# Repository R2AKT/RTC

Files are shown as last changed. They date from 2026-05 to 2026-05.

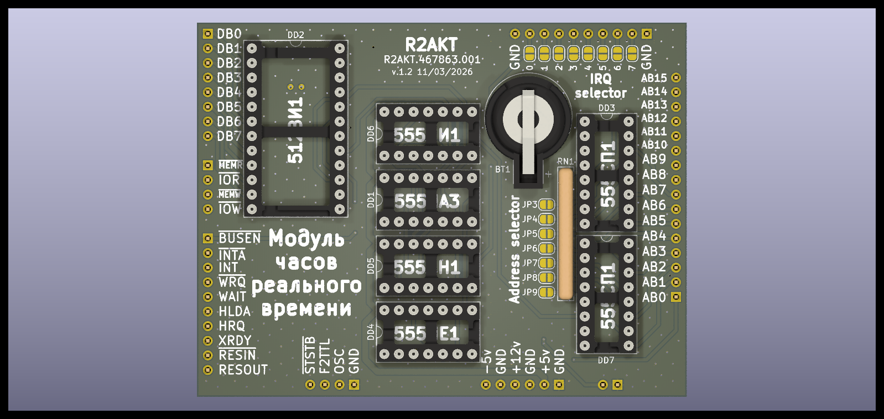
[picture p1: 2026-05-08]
RTC_top.png

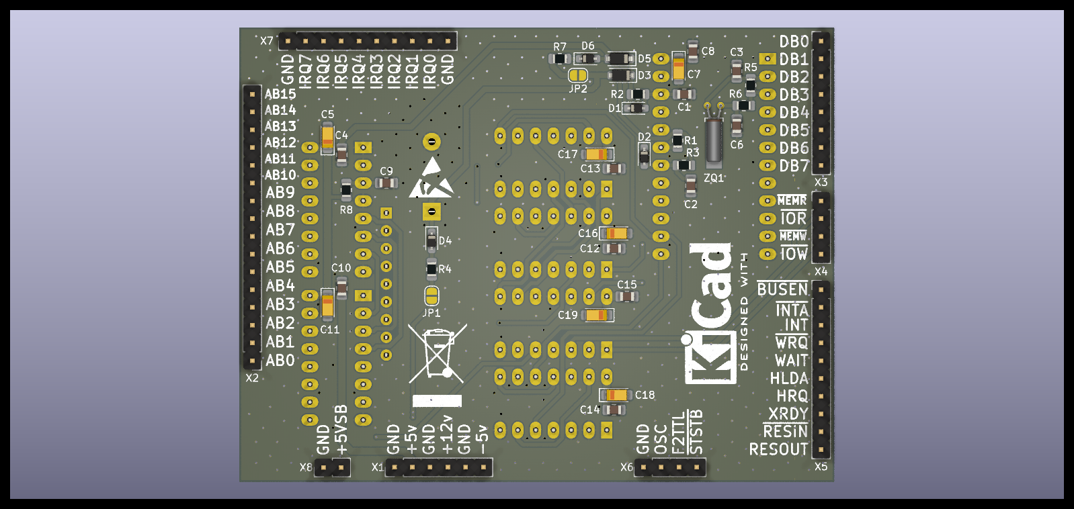
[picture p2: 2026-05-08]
RTC_btn.png

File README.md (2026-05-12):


License addendum - https://github.com/R2AKT/RTC/blob/main/Addendum.txt
# RTC
Real-time clock module (RTC). For connection to the CPU_8080 processor board - https://github.com/R2AKT/CPU_8080.

Based on a real-time clock for RADIO-86RK.

Status: testing and writing the driver.

Модуль часов реального времени (RTC). Для подключения к процессорной плате CPU_8080 - https://github.com/R2AKT/CPU_8080.

На базе часов реального времени для РАДИО-86РК.

Статус: в процессе тестирования и написания драйвера.

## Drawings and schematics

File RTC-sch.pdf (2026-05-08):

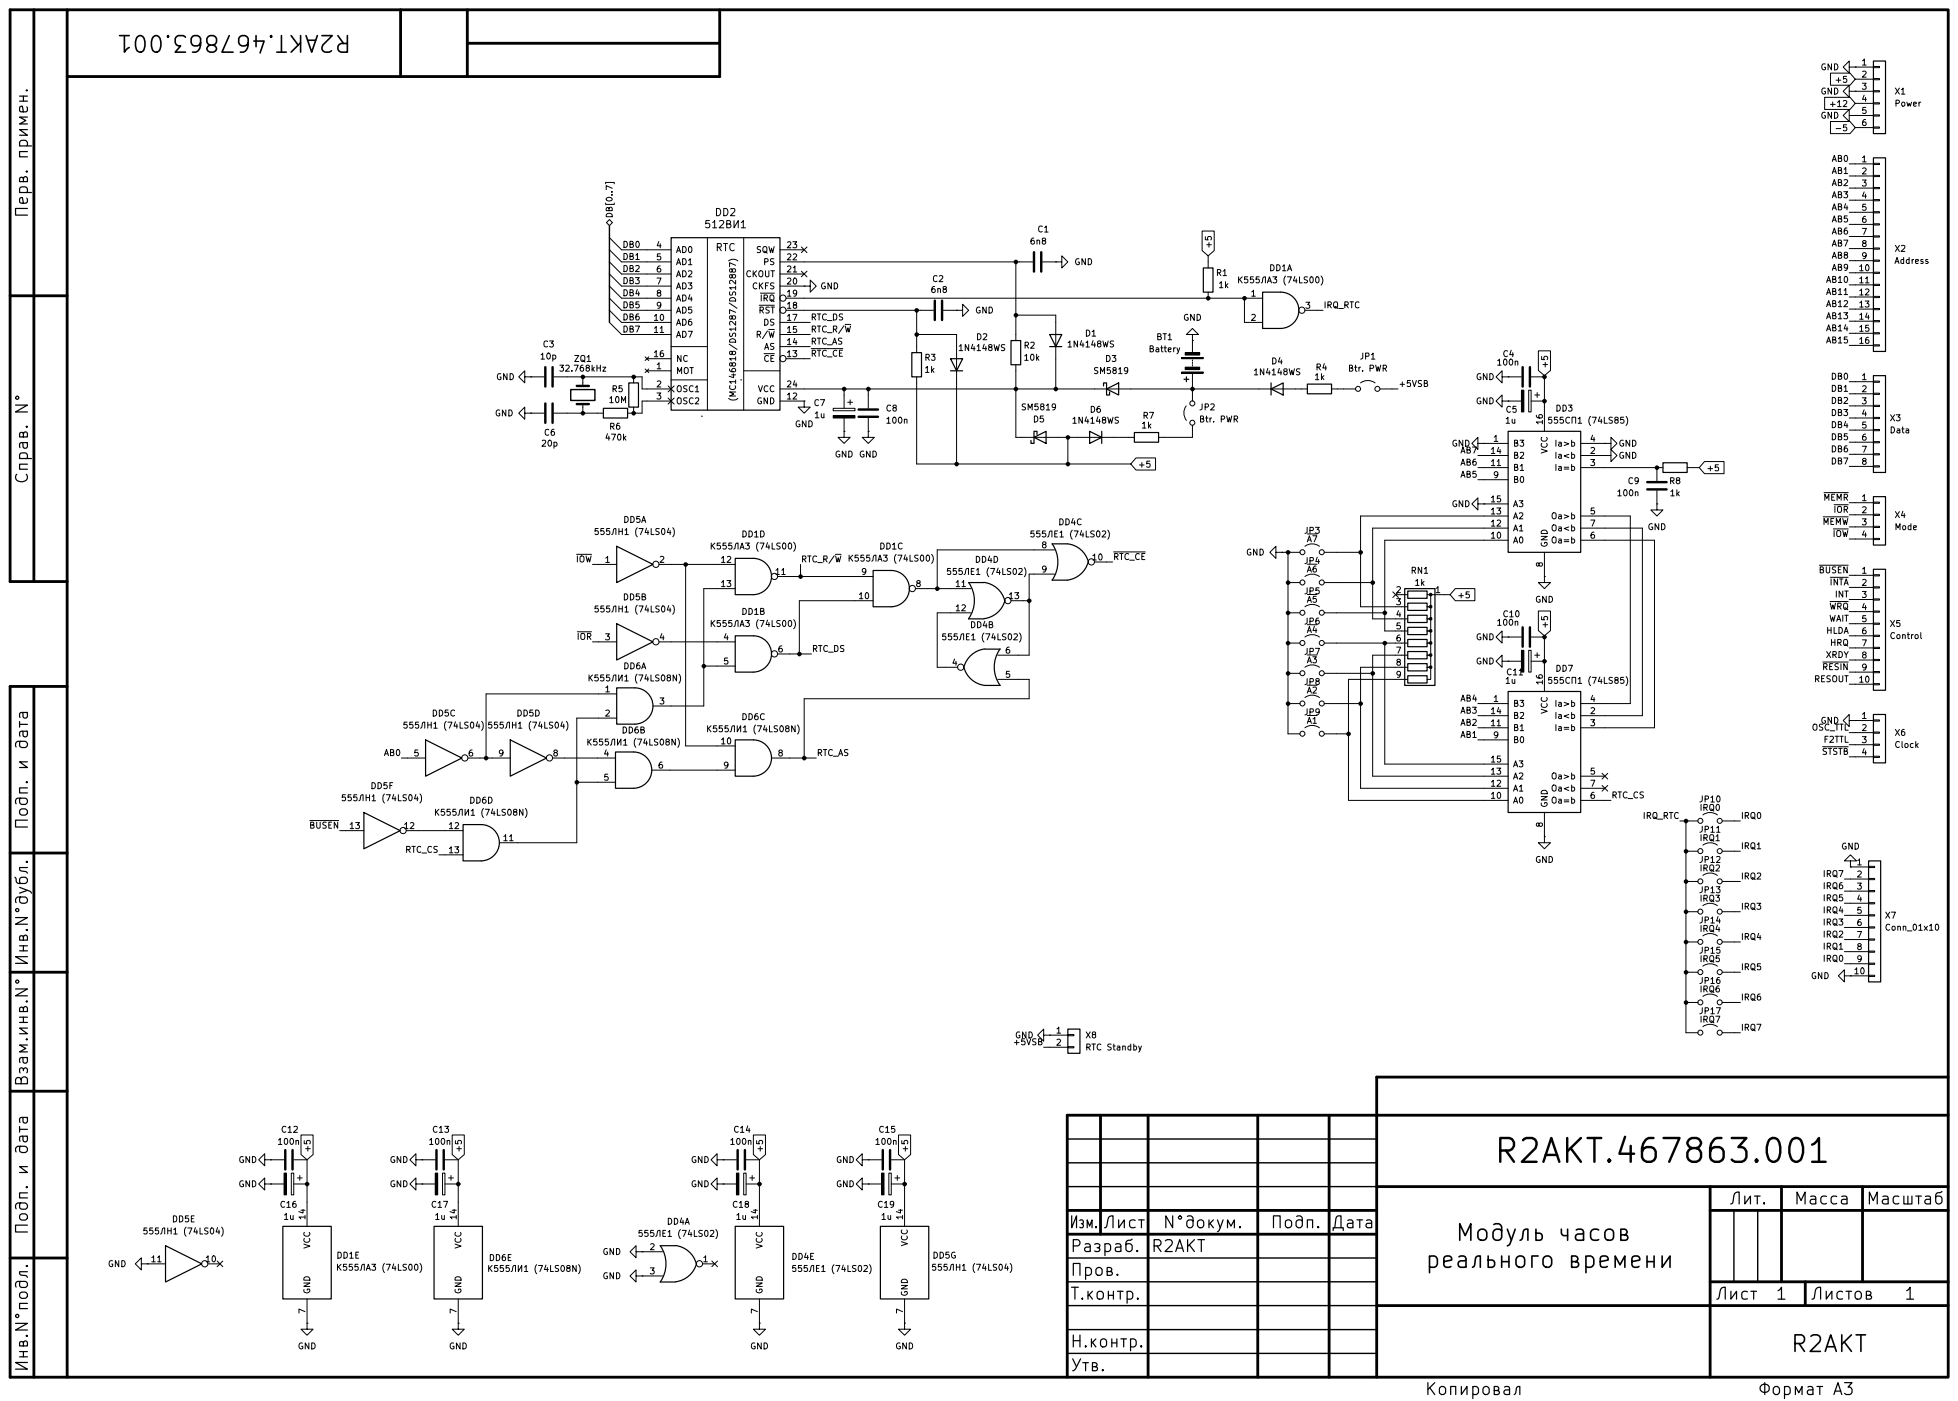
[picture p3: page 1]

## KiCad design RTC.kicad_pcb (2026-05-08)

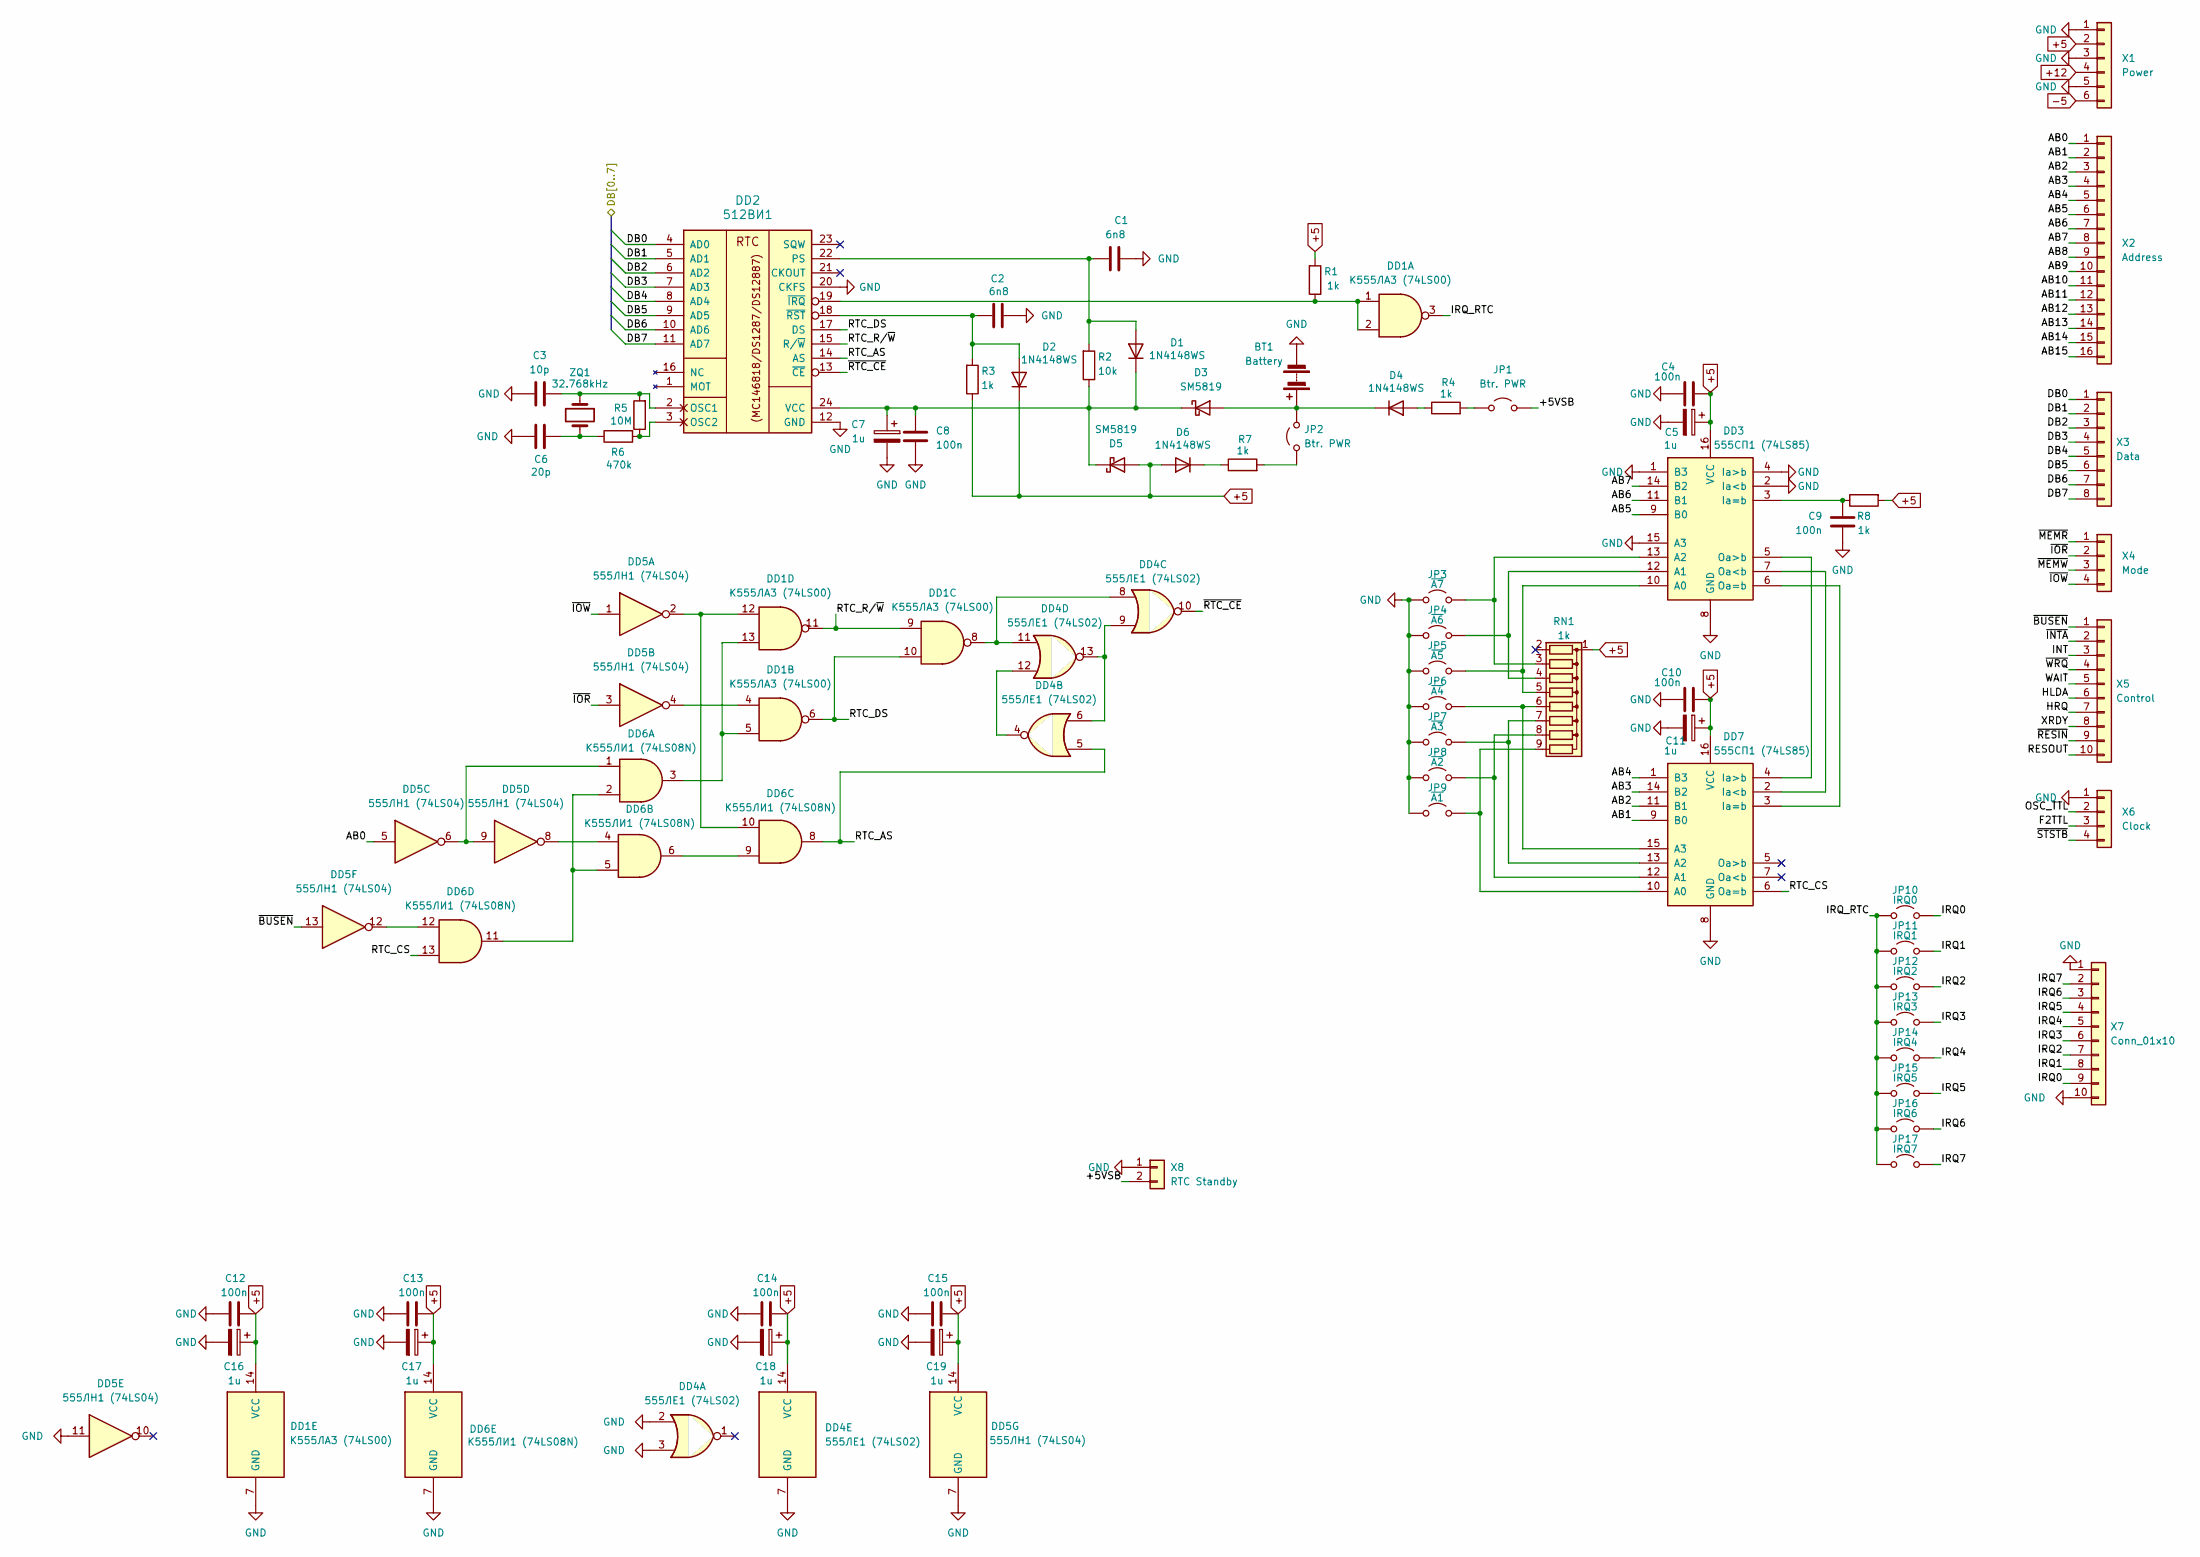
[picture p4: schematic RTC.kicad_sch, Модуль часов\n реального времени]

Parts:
BT1: Battery; BatteryHolder_Keystone_500
C1, C2: 6n8; C_0805_2012Metric_Pad1.18x1.45mm_HandSolder
C3: 10p; C_0805_2012Metric_Pad1.18x1.45mm_HandSolder
C4, C8, C9, C10, C12, C13, C14, C15: 100n; C_0805_2012Metric_Pad1.18x1.45mm_HandSolder
C5, C7, C11, C16, C17, C18, C19: 1u; CP_EIA-3216-18_Kemet-A_Pad1.58x1.35mm_HandSolder
C6: 20p; C_0805_2012Metric_Pad1.18x1.45mm_HandSolder
D1, D2, D4, D6: 1N4148WS; D_SOD-323_HandSoldering
D3: SM5819; D_SOD-123F
D5: SM5819; D_SOD-123
DD1: К555ЛА3 (74LS00); DIP-14_W7.62mm_Socket_LongPads
DD2: 512ВИ1; DIP-24_W15.24mm_Socket_LongPads
DD3, DD7: 555СП1 (74LS85); DIP-16_W7.62mm_Socket_LongPads
DD4: 555ЛЕ1 (74LS02); DIP-14_W7.62mm_Socket_LongPads
DD5: 555ЛН1 (74LS04); DIP-14_W7.62mm_Socket_LongPads
DD6: К555ЛИ1 (74LS08N); DIP-14_W7.62mm_Socket_LongPads
JP1, JP2: Btr. PWR; SolderJumper-2_P1.3mm_Open_RoundedPad1.0x1.5mm
JP3: ~{A7}; SolderJumper-2_P1.3mm_Open_RoundedPad1.0x1.5mm
JP4: ~{A6}; SolderJumper-2_P1.3mm_Open_RoundedPad1.0x1.5mm
JP5: ~{A5}; SolderJumper-2_P1.3mm_Open_RoundedPad1.0x1.5mm
JP6: ~{A4}; SolderJumper-2_P1.3mm_Open_RoundedPad1.0x1.5mm
JP7: ~{A3}; SolderJumper-2_P1.3mm_Open_RoundedPad1.0x1.5mm
JP8: ~{A2}; SolderJumper-2_P1.3mm_Open_RoundedPad1.0x1.5mm
JP9: ~{A1}; SolderJumper-2_P1.3mm_Open_RoundedPad1.0x1.5mm
JP10: IRQ0; SolderJumper-2_P1.3mm_Open_RoundedPad1.0x1.5mm
JP11: IRQ1; SolderJumper-2_P1.3mm_Open_RoundedPad1.0x1.5mm
JP12: IRQ2; SolderJumper-2_P1.3mm_Open_RoundedPad1.0x1.5mm
JP13: IRQ3; SolderJumper-2_P1.3mm_Open_RoundedPad1.0x1.5mm
JP14: IRQ4; SolderJumper-2_P1.3mm_Open_RoundedPad1.0x1.5mm
JP15: IRQ5; SolderJumper-2_P1.3mm_Open_RoundedPad1.0x1.5mm
JP16: IRQ6; SolderJumper-2_P1.3mm_Open_RoundedPad1.0x1.5mm
JP17: IRQ7; SolderJumper-2_P1.3mm_Open_RoundedPad1.0x1.5mm
R1, R3, R4, R7, R8: 1k; R_0805_2012Metric_Pad1.20x1.40mm_HandSolder
R2: 10k; R_0805_2012Metric_Pad1.20x1.40mm_HandSolder
R5: 10M; R_0805_2012Metric_Pad1.20x1.40mm_HandSolder
R6: 470k; R_0805_2012Metric_Pad1.20x1.40mm_HandSolder
RN1: 1k; R_Array_SIP9
X1: Power; PinHeader_1x06_P2.54mm_Vertical
X2: Address; PinHeader_1x16_P2.54mm_Vertical
X3: Data; PinHeader_1x08_P2.54mm_Vertical
X4: Mode; PinHeader_1x04_P2.54mm_Vertical
X5: Control; PinHeader_1x10_P2.54mm_Vertical
X6: Clock; PinHeader_1x04_P2.54mm_Vertical
X7: Conn_01x10; PinHeader_1x10_P2.54mm_Vertical
X8: RTC Standby; PinHeader_1x02_P2.54mm_Vertical
ZQ1: 32.768kHz; Crystal_C26-LF_D2.1mm_L6.5mm_Horizontal_1EP_style1

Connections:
+5: C4.1, C5.1, C10.1, C11.1, C12.1, C13.1, C14.1, C15.1, C16.1, C17.1, C18.1, C19.1, D2.1 (K), D5.2 (A), D6.2 (A), DD1.14 (VCC), DD3.16 (VCC), DD4.14 (VCC), DD5.14 (VCC), DD6.14 (VCC), DD7.16 (VCC), R1.2, R3.1, R8.2, RN1.1 (common), X1.2
+12: X1.4
-5: X1.6
/+5VSB: JP1.2 (B), X8.2
/AB0: DD5.5, X2.1
/AB1: DD7.9 (B0), X2.2
/AB2: DD7.11 (B1), X2.3
/AB3: DD7.14 (B2), X2.4
/AB4: DD7.1 (B3), X2.5
/AB5: DD3.9 (B0), X2.6
/AB6: DD3.11 (B1), X2.7
/AB7: DD3.14 (B2), X2.8
/AB8: X2.9
/AB9: X2.10
/AB10: X2.11
/AB11: X2.12
/AB12: X2.13
/AB13: X2.14
/AB14: X2.15
/AB15: X2.16
/DB0: DD2.4 (AD0), X3.1
/DB1: DD2.5 (AD1), X3.2
/DB2: DD2.6 (AD2), X3.3
/DB3: DD2.7 (AD3), X3.4
/DB4: DD2.8 (AD4), X3.5
/DB5: DD2.9 (AD5), X3.6
/DB6: DD2.10 (AD6), X3.7
/DB7: DD2.11 (AD7), X3.8
/F2TTL: X6.3
/HLDA: X5.6
/HRQ: X5.7
/INT: X5.3
/IRQ0: JP10.2 (B), X7.9
/IRQ1: JP11.2 (B), X7.8
/IRQ2: JP12.2 (B), X7.7
/IRQ3: JP13.2 (B), X7.6
/IRQ4: JP14.2 (B), X7.5
/IRQ5: JP15.2 (B), X7.4
/IRQ6: JP16.2 (B), X7.3
/IRQ7: JP17.2 (B), X7.2
/IRQ_RTC: DD1.3, JP10.1 (A), JP11.1 (A), JP12.1 (A), JP13.1 (A), JP14.1 (A), JP15.1 (A), JP16.1 (A), JP17.1 (A)
/OSC_TTL: X6.2
/RESOUT: X5.10
/RTC_AS: DD2.14 (AS), DD4.5, DD6.8
/RTC_CS: DD6.13, DD7.6 (Oa=b)
/RTC_DS: DD1.6, DD1.10, DD2.17 (DS)
/RTC_R/~W: DD1.9, DD1.11, DD2.15 (R/~W)
/WAIT: X5.5
/XRDY: X5.8
/~BUSEN: DD5.13, X5.1
/~INTA: X5.2
/~IOR: DD5.3, X4.2
/~IOW: DD5.1, X4.4
/~MEMR: X4.1
/~MEMW: X4.3
/~RESIN: X5.9
/~RTC_CE: DD2.13 (~CE), DD4.10
/~STSTB: X6.4
/~WRQ: X5.4
GND: BT1.2 (-), C1.2, C2.2, C3.1, C4.2, C5.2, C6.1, C7.2, C8.2, C9.2, C10.2, C11.2, C12.2, C13.2, C14.2, C15.2, C16.2, C17.2, C18.2, C19.2, DD1.7 (GND), DD2.12 (GND), DD2.20 (CKFS), DD3.1 (B3), DD3.2 (Ia<b), DD3.4 (Ia>b), DD3.8 (GND), DD3.15 (A3), DD4.2, DD4.3, DD4.7 (GND), DD5.7 (GND), DD5.11, DD6.7 (GND), DD7.8 (GND), JP3.1 (A), JP4.1 (A), JP5.1 (A), JP6.1 (A), JP7.1 (A), JP8.1 (A), JP9.1 (A), X1.1, X1.3, X1.5, X6.1, X7.1, X7.10, X8.1
unnamed: BT1.1 (+), D3.2 (A), D4.1 (K), JP2.2 (B)
unnamed: C6.2, R6.1, ZQ1.2
unnamed: C1.1, D1.2 (A), DD2.22 (PS), R2.2
unnamed: C7.1, C8.1, D1.1 (K), D3.1 (K), D5.1 (K), DD2.24 (VCC), R2.1
unnamed: C2.1, D2.2 (A), DD2.18 (~RST), R3.2
unnamed: D4.2 (A), R4.1
unnamed: D6.1 (K), R7.1
unnamed: DD1.4, DD5.4
unnamed: DD1.8, DD4.8, DD4.11
unnamed: DD1.12, DD5.2, DD6.10
unnamed: DD1.5, DD1.13, DD6.3
unnamed: C3.2, DD2.2 (OSC1), R5.2, ZQ1.1
unnamed: DD2.3 (OSC2), R5.1, R6.2
unnamed: DD1.1, DD1.2, DD2.19 (~IRQ), R1.1
unnamed: DD3.10 (A0), JP5.2 (B), RN1.5 (R4)
unnamed: DD3.12 (A1), JP4.2 (B), RN1.4 (R3)
unnamed: DD3.13 (A2), JP3.2 (B), RN1.3 (R2)
unnamed: C9.1, DD3.3 (Ia=b), R8.1
unnamed: DD3.7 (Oa<b), DD7.2 (Ia<b)
unnamed: DD3.6 (Oa=b), DD7.3 (Ia=b)
unnamed: DD3.5 (Oa>b), DD7.4 (Ia>b)
unnamed: DD4.4, DD4.12
unnamed: DD4.6, DD4.9, DD4.13
unnamed: DD5.6, DD5.9, DD6.1
unnamed: DD5.8, DD6.4
unnamed: DD5.12, DD6.12
unnamed: DD6.6, DD6.9
unnamed: DD6.2, DD6.5, DD6.11
unnamed: DD7.10 (A0), JP9.2 (B), RN1.9 (R8)
unnamed: DD7.12 (A1), JP8.2 (B), RN1.8 (R7)
unnamed: DD7.13 (A2), JP7.2 (B), RN1.7 (R6)
unnamed: DD7.15 (A3), JP6.2 (B), RN1.6 (R5)
unnamed: JP1.1 (A), R4.2
unnamed: JP2.1 (A), R7.2

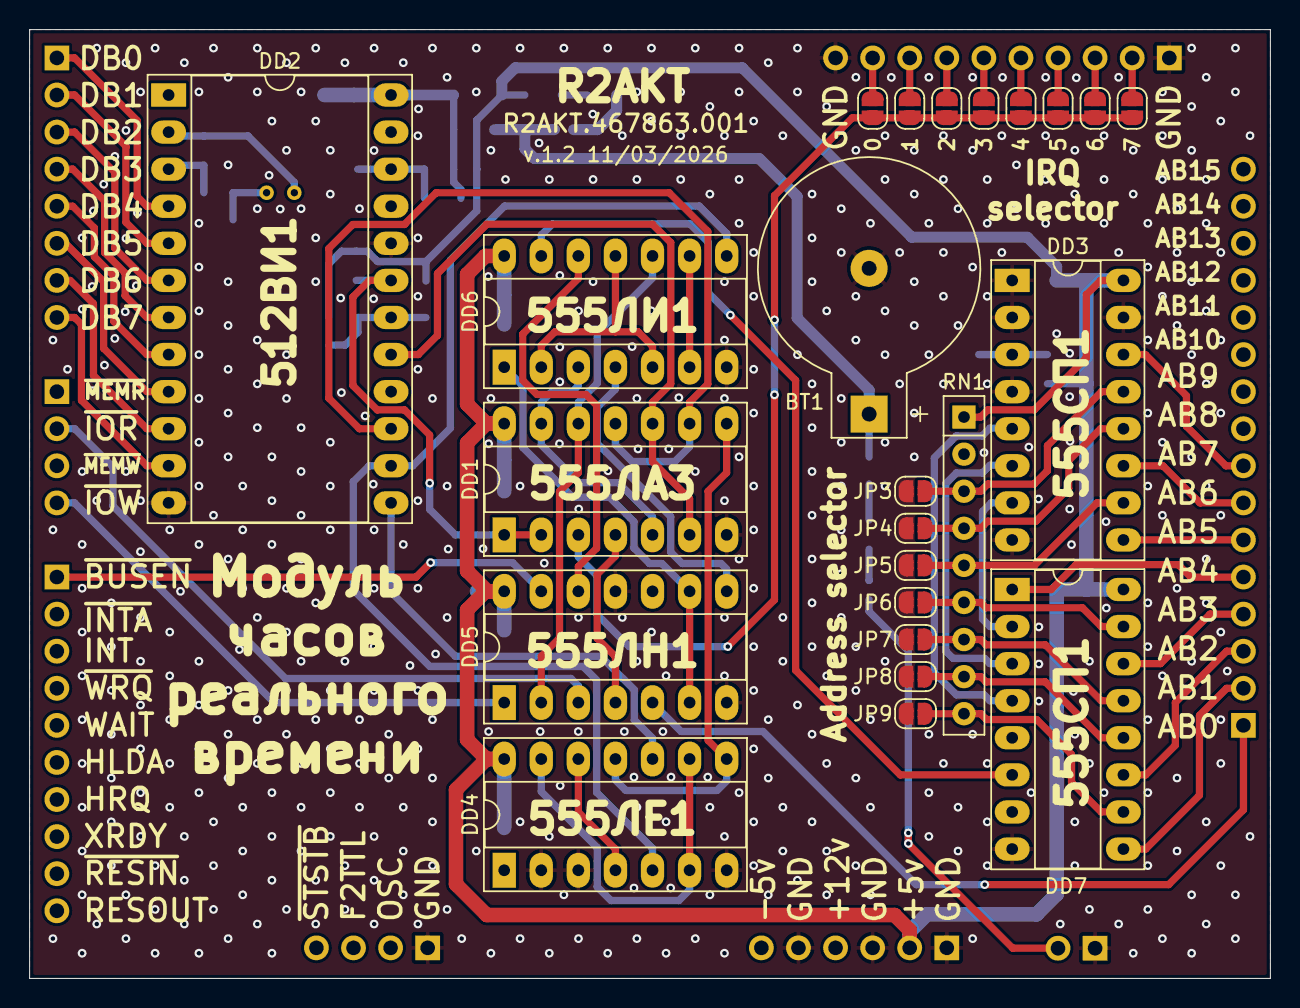
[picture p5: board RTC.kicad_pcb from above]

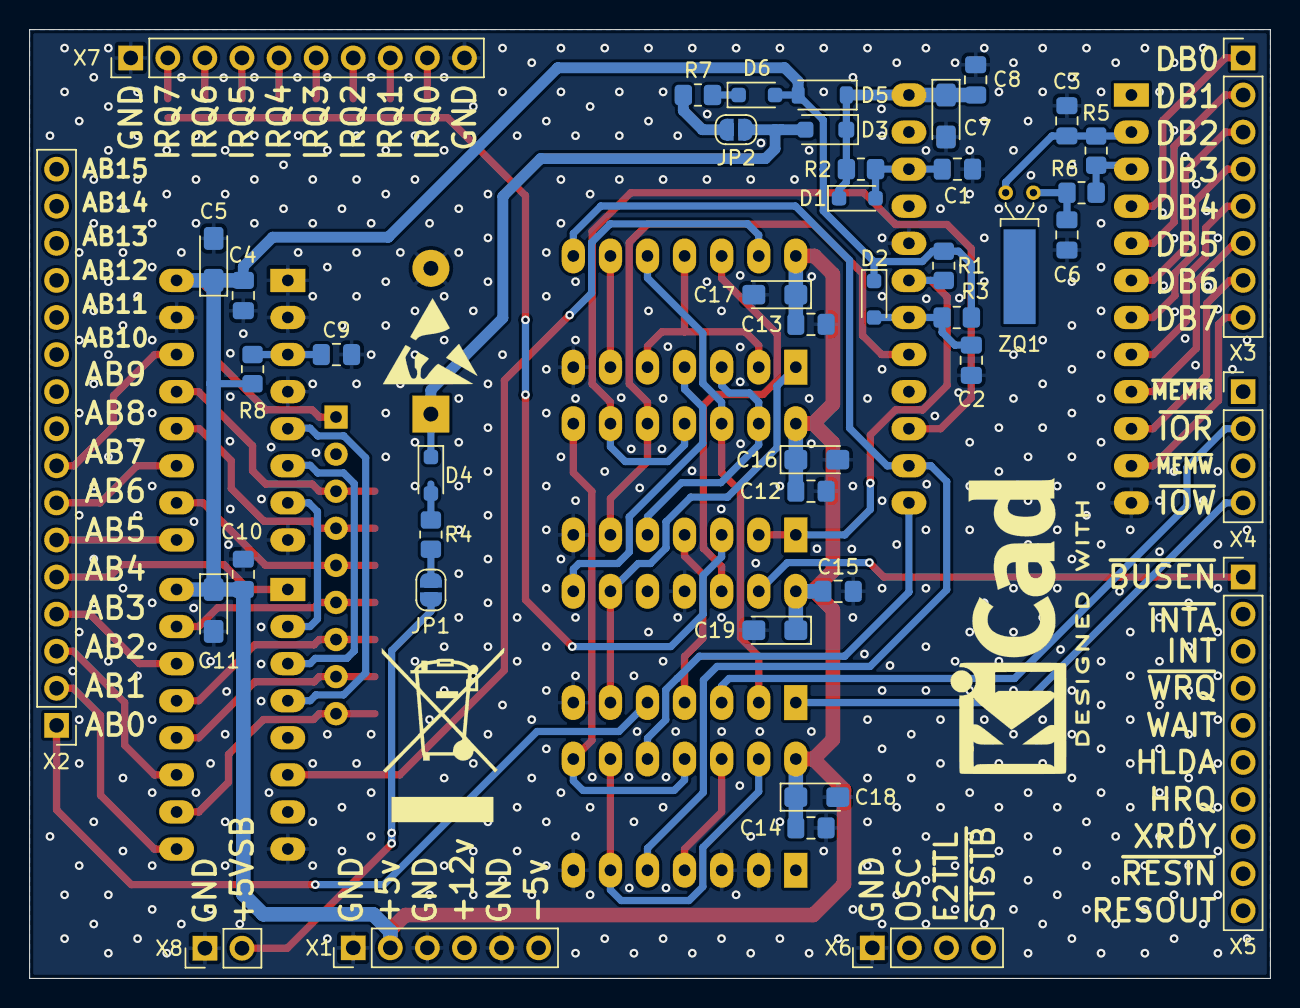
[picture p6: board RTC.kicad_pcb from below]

Board: 2 copper layers, 85.0 x 65.0 mm, 68 parts (44 on the bottom side), 70 nets.

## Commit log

2026-02-20 Add files via upload
    Changed chip power-up reset schemtic, added IRQ option, fix silk problem.
    Изменена схема сброса часов при подаче питания, добавлена опция IRQ, исправлены проблемы с шелкографией.
    [RTC.kicad_pcb, RTC.kicad_sch]
2026-03-11 Add files via upload
    Fix start-up reset issue
    Устранение проблемы начального сброса
    [RTC.kicad_pcb, RTC.kicad_sch]

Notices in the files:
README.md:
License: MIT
